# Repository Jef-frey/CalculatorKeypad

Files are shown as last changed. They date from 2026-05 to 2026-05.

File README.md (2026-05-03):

# CalculatorKeypad(WIP)
This project is still a work in progress, the goal is to create a device that can switch between calculator and computer keypad function with the flip of a switch 
keypad_mode
calculator_mode

# Requirements
## Hardware
1x OLIMEX ESP32-S3-DevKit-LiPo development board<br />
1x OLED display<br />
1x battery<br />
1x USB cables<br />
2x slide switch<br />
Switches that fit your application (17 for my project)<br />

## Software
Arduino IDE<br />
U8G2 library<br />
 
# Connection
Pins used and connected for the OLED display are written on the [`oled.cpp`](software/oled.cpp) file and the changable pins are stored on the [`oled.h`](software/oled.h) file, they are for the SPI 256x64 OLED Display with Screen Driver SH1122 used in my project, if a different display is used, a different u8g2 constructor may be used with different connections. And the SPI pins for the OLED display may also need to be changed if a different development board is used.<br />
Pins used for the keypad connections are written on the [`keyboard.h`](software/keyboard.h) file inside the variables KEY_PINS and MODE_SEL_PIN, different pins on the board can be used if available.<br />

# Battery Voltage
The original code from Olimex for battery voltage reading reads the voltage level, to display the voltage as a percentage, a script called [`plotVoltage.ino`](software/battery_level/plotVoltage.ino) is created. It measures the voltage and the time of the measurement and prints the measured values upon request. Part of this code is modified from https://dronebotworkshop.com/esp32-non-volatile-storage/ <br />
To use this script:
1. upload the script with the necessary include files at the same directory
2. charge the device with the battery until it is full
3. unplug the device and press '1' on the keypad
4. wait until the display no longer lights up (run out of power)
5. prepare a program that can accept UART signal and turn the data into a csv file (I used Tera Term for this step)
6. plug in the device at the UART port and press '2' on the keypad
7. plot the csv file

For instance this is the plot of the 420mAh Lipo battery I use
Battery voltage output level curve

# Reference
Software related to battery sensing is from OLIMEX, it's license GPL3 is included in this repository <br />
https://github.com/OLIMEX/ESP32-S3-DevKit-LiPo/blob/main/SOFTWARE/Arduino/ESP32-S3-DevKit-Lipo-bat-sense/ESP32-S3-DevKit-Lipo-bat-sense.ino <br />
Software related to storing data in esp32 and outputing data from esp32 is from https://dronebotworkshop.com/esp32-non-volatile-storage/

# Future plans
Add a case for the device<br />
CalculatorKeypad_case

Use ESP32S3 module instead of a development board, as the development board uses voltage dividers that contribute to leakage current<br />
Implement Bluetooth feature for the keypad<br />

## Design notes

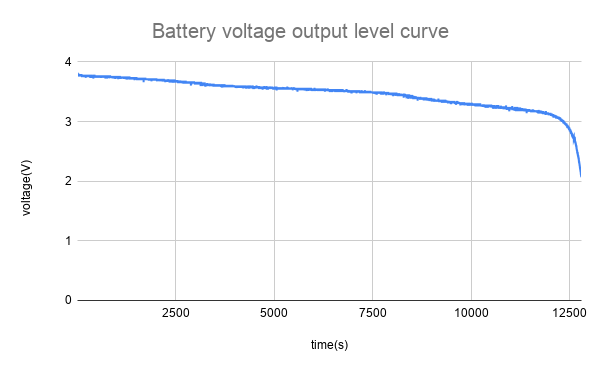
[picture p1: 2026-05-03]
software/battery_level/Battery voltage output level curve.png

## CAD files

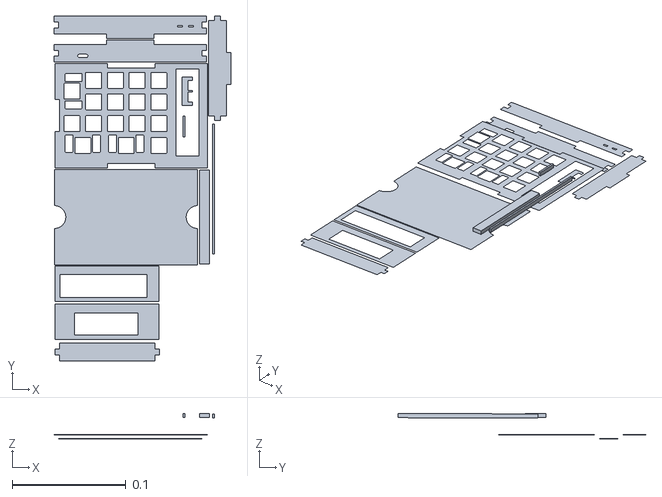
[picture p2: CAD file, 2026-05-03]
hardware/case/cal_numpad.dxf
0.155 x 0.303 x 0.0222

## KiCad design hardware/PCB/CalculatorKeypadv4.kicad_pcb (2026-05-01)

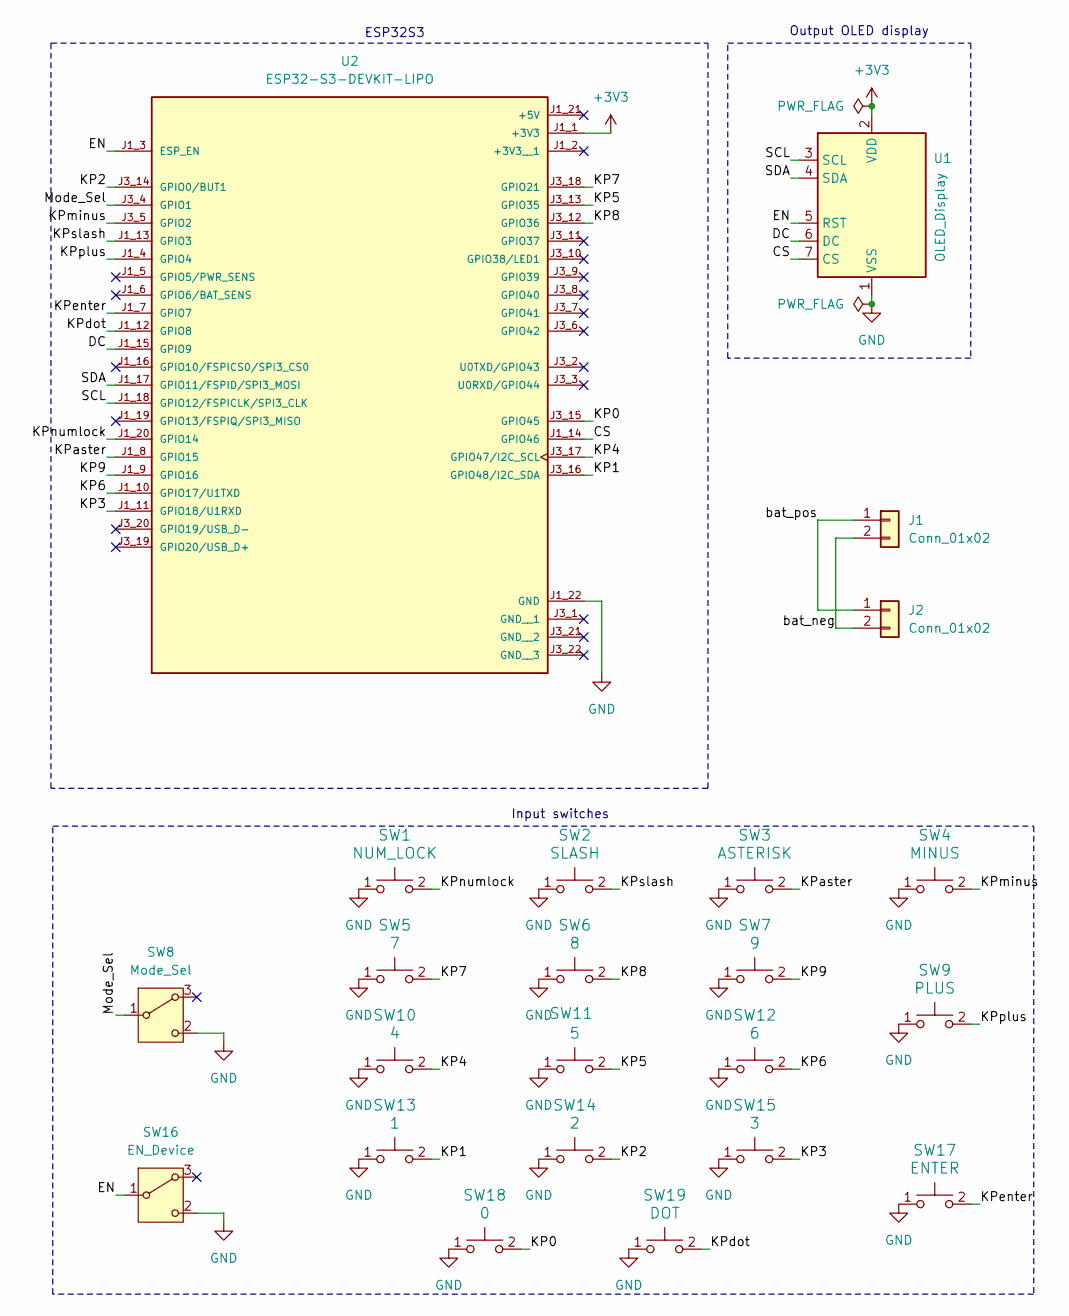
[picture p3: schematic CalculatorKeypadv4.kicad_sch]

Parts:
J1: Conn_01x02; JST_PH_B2B-PH-K_1x02_P2.00mm_Vertical
J2: Conn_01x02; JST_PH_S2B-PH-K_1x02_P2.00mm_Horizontal
SW1: NUM_LOCK; SW_Cherry_MX_1.00u_Plate_w_3Dmodel
SW2: SLASH; SW_Cherry_MX_1.00u_Plate_w_3Dmodel
SW3: ASTERISK; SW_Cherry_MX_1.00u_Plate_w_3Dmodel
SW4: MINUS; SW_Cherry_MX_1.00u_Plate_w_3Dmodel
SW5: 7; SW_Cherry_MX_1.00u_Plate_w_3Dmodel
SW6: 8; SW_Cherry_MX_1.00u_Plate_w_3Dmodel
SW7: 9; SW_Cherry_MX_1.00u_Plate_w_3Dmodel
SW8: Mode_Sel; slide_switch
SW9: PLUS; SW_Cherry_MX_2.00u_Vertical_Plate
SW10: 4; SW_Cherry_MX_1.00u_Plate_w_3Dmodel
SW11: 5; SW_Cherry_MX_1.00u_Plate_w_3Dmodel
SW12: 6; SW_Cherry_MX_1.00u_Plate_w_3Dmodel
SW13: 1; SW_Cherry_MX_1.00u_Plate_w_3Dmodel
SW14: 2; SW_Cherry_MX_1.00u_Plate_w_3Dmodel
SW15: 3; SW_Cherry_MX_1.00u_Plate_w_3Dmodel
SW16: EN_Device; slide_switch
SW17: ENTER; SW_Cherry_MX_2.00u_Vertical_Plate
SW18: 0; SW_Cherry_MX_2.00u_Plate
SW19: DOT; SW_Cherry_MX_1.00u_Plate_w_3Dmodel
U1: OLED_Display; OLED_display
U2: ESP32-S3-DEVKIT-LIPO; XCVR_ESP32-S3-DEVKIT-LIPO; PARTREV B

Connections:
+3V3: U1.2 (VDD), U2.J1_1 (+3V3)
/CS: U1.7 (CS), U2.J1_14 (GPIO46)
/DC: U1.6 (DC), U2.J1_15 (GPIO9)
/EN: SW16.1 (B), U1.5 (RST), U2.J1_3 (ESP_EN)
/KP0: SW18.2, U2.J3_15 (GPIO45)
/KP1: SW13.2, U2.J3_16 (GPIO48/I2C_SDA)
/KP2: SW14.2, U2.J3_14 (GPIO0/BUT1)
/KP3: SW15.2, U2.J1_11 (GPIO18/U1RXD)
/KP4: SW10.2, U2.J3_17 (GPIO47/I2C_SCL)
/KP5: SW11.2, U2.J3_13 (GPIO35)
/KP6: SW12.2, U2.J1_10 (GPIO17/U1TXD)
/KP7: SW5.2, U2.J3_18 (GPIO21)
/KP8: SW6.2, U2.J3_12 (GPIO36)
/KP9: SW7.2, U2.J1_9 (GPIO16)
/KPaster: SW3.2, U2.J1_8 (GPIO15)
/KPdot: SW19.2, U2.J1_12 (GPIO8)
/KPenter: SW17.2, U2.J1_7 (GPIO7)
/KPminus: SW4.2, U2.J3_5 (GPIO2)
/KPnumlock: SW1.2, U2.J1_20 (GPIO14)
/KPplus: SW9.2, U2.J1_4 (GPIO4)
/KPslash: SW2.2, U2.J1_13 (GPIO3)
/Mode_Sel: SW8.1 (B), U2.J3_4 (GPIO1)
/SCL: U1.3 (SCL), U2.J1_18 (GPIO12/FSPICLK/SPI3_CLK)
/SDA: U1.4 (SDA), U2.J1_17 (GPIO11/FSPID/SPI3_MOSI)
/bat_neg: J1.2, J2.2
/bat_pos: J1.1, J2.1
GND: SW1.1, SW2.1, SW3.1, SW4.1, SW5.1, SW6.1, SW7.1, SW8.2 (C), SW9.1, SW10.1, SW11.1, SW12.1, SW13.1, SW14.1, SW15.1, SW16.2 (C), SW17.1, SW18.1, SW19.1, U1.1 (VSS), U2.J1_22 (GND)

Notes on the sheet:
ESP32S3
Input switches
Output OLED display

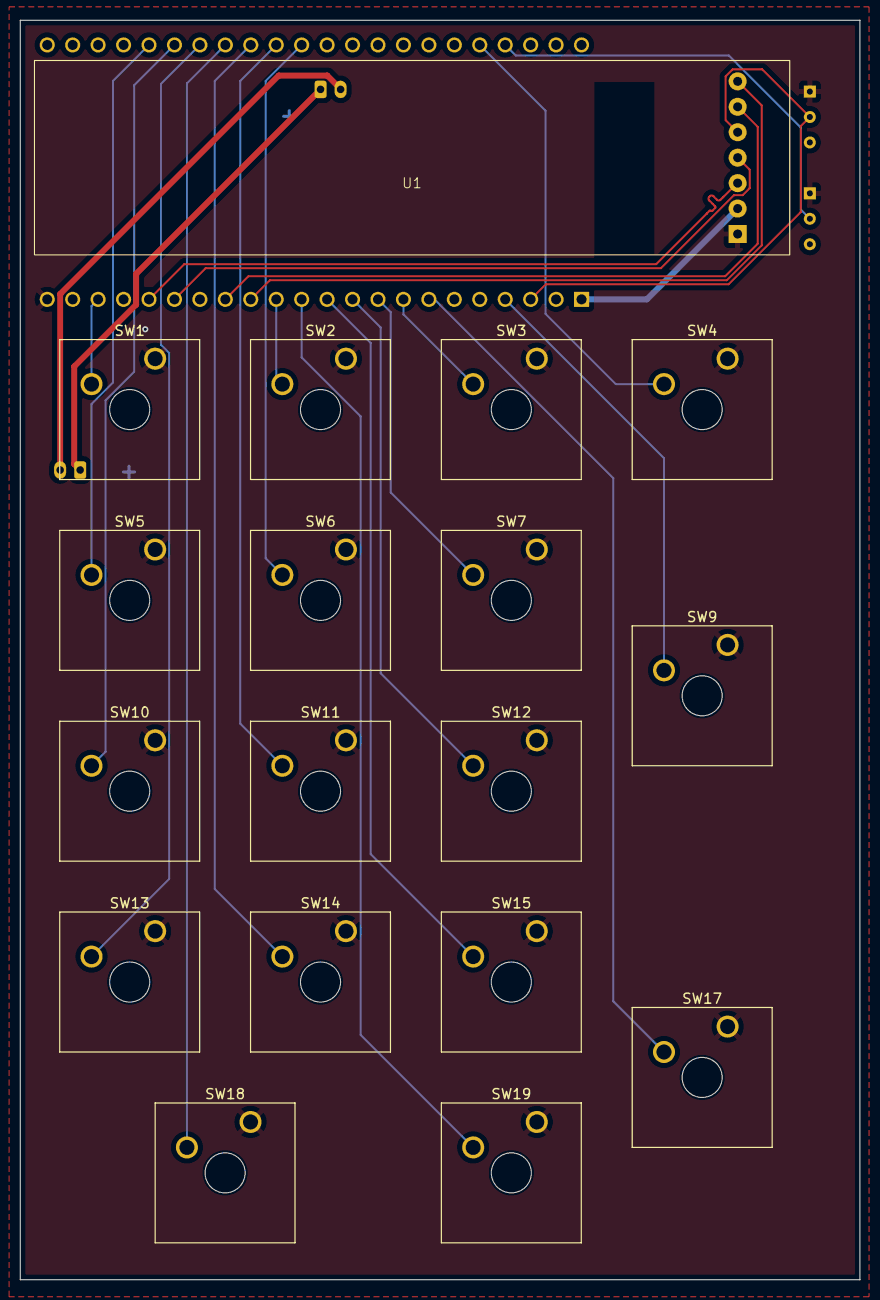
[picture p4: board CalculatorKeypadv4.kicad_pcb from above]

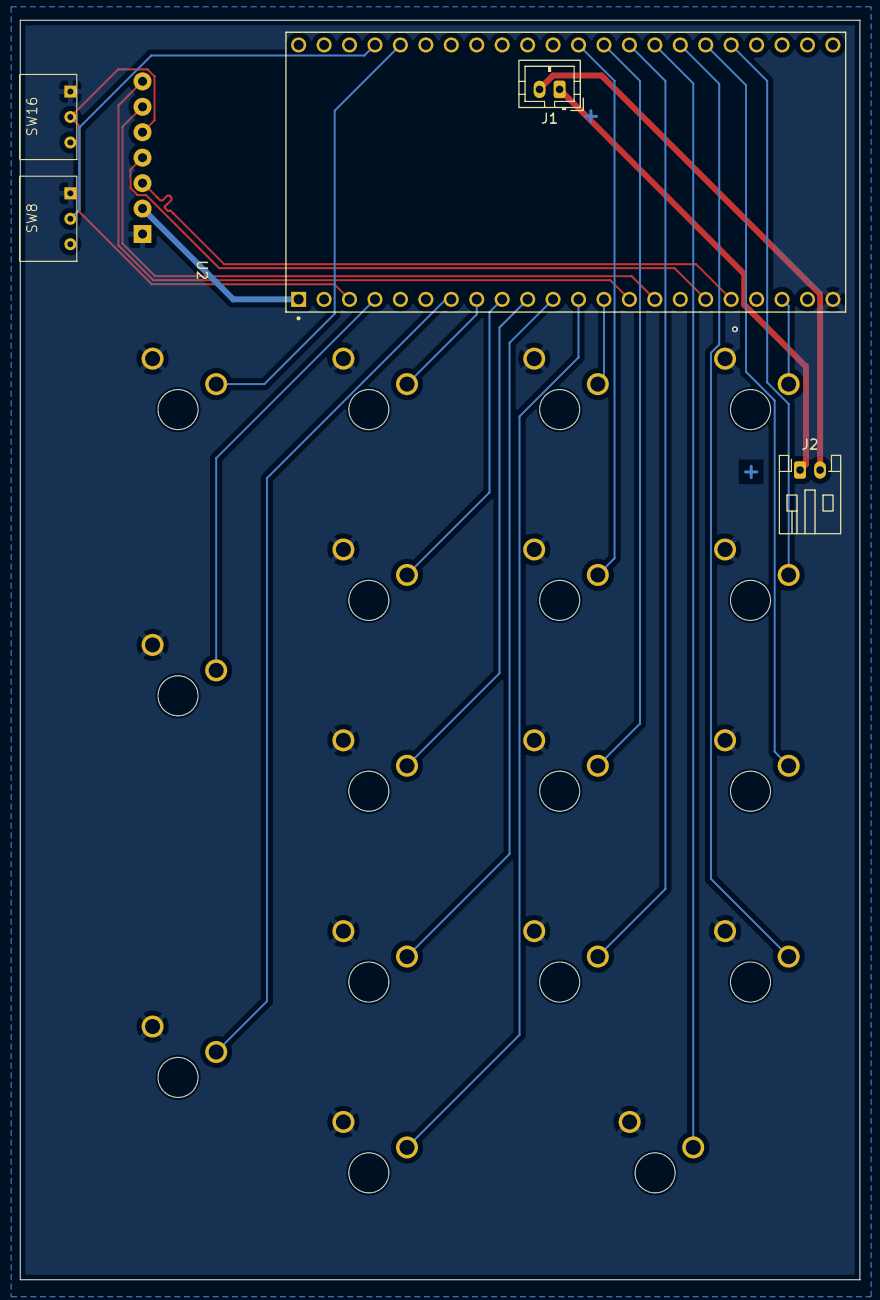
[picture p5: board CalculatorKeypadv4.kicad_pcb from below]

Board: 2 copper layers, 83.8 x 125.7 mm, 23 parts (5 on the bottom side), 27 nets.

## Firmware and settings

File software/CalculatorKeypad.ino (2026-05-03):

#include "control.h"
#include "oled.h"

#include "calculator.h"
#include "calculator_display.h"
#include "keyboard.h"
#include "LinkedList.h"

#include "USB.h"
#include "USBHIDKeyboard.h"

char read_switch;
calculator cal;
USBHIDKeyboard Keyboard;
calculatorkeypad_mode device_mode; 
battery battery_status;
int bat_flag = 1;

void IRAM_ATTR device_mode_control() {
  if (digitalRead(MODE_SEL_PIN) == HIGH) {
    cal.calculator_on();
    device_mode = calculator_mode;
  } else {
    bat_flag = 1;
    battery_status = get_bat_status(bat_flag);
    print_battery(battery_status);
    device_mode = keypad_mode;
    bat_flag = 0;
  }
}

void setup() {  
  // initialization
  control_initialize();
  keyboard_initialize();
  oled_initialize();

  Keyboard.begin();
  USB.begin();

  attachInterrupt(MODE_SEL_PIN, device_mode_control, CHANGE);

  // display the screen's initial state 
  device_mode_control();

}

void loop() {
  read_switch = get_pressed_switch(device_mode);

  if (read_switch != '?') {
    if (device_mode == keypad_mode) {
      Keyboard.write(read_switch);
    } else {
      cal.operate_input(read_switch);
    }
  }

  if (device_mode == keypad_mode) {
    battery_status = get_bat_status(bat_flag);
    print_battery(battery_status);
  }
}

// 

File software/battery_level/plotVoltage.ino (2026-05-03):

// This program stores a csv file of the voltage level of the battery with respect to time
// Pressing "1" in the keypad will start storing the values and pressing "2" of the keypad will upload the file via Serial UART
// Part of the code are modified from https://dronebotworkshop.com/esp32-non-volatile-storage/

#include "control.h"
#include "oled.h"

#include "calculator_display.h"
#include "keyboard.h"

char read_switch;

display_buf display;
calculatorkeypad_mode device_mode = calculator_mode; 

#include <FS.h>
#include <LittleFS.h>

const char* FILE_PATH = "/bat_lvl.csv";
char buf[ARR_SIZE];
int write_flag = 0;
File fh;
#define LOG_INTERVAL 1000
int count = 0;
float voltage_sum = 0;

void setup() {  
  // initialization
  control_initialize();
  keyboard_initialize();
  oled_initialize();
  Serial.begin(115200);

  if (!LittleFS.begin(true)) {
    strcpy(display.top_display,"ERROR: mounting fail");
    print_calculator(display);
    return; 
  } else {
    strcpy(display.top_display,"Device ready");
    print_calculator(display);
  }

}

void loop() {
  read_switch = get_pressed_switch(device_mode);

  if (read_switch == '1') {
    if (write_flag == 0) {
      write_flag = 1;
    } else {
      write_flag = 0;
    }
  } else if (read_switch == '2') {
    String("Uploading file").toCharArray(buf, ARR_SIZE);
    strcpy(display.top_display,buf);
    print_calculator(display);

    fh = LittleFS.open(FILE_PATH, FILE_READ);
    while (fh.available()) {
      Serial.write(fh.read());
    }
    fh.close();

    String("Upload completed").toCharArray(buf, ARR_SIZE);
    strcpy(display.top_display,buf);
    print_calculator(display);

    delay(1000);
  }

  if (write_flag == 1) {
    fh = LittleFS.open(FILE_PATH, FILE_WRITE);
    fh.println("time(s),voltage(V)");
    fh.close();
    write_flag = 2;

    strcpy(display.top_display,"Recording starts");
    print_calculator(display);
    delay(1000);
  } else if (write_flag == 2){

    count++;
    voltage_sum+=readVoltage(BAT_ADC_PIN, BAT_DIVIDER_RATIO);

    static uint32_t t0 = 0;

    if (millis() - t0 >= 1000) {
      t0 = millis();

      String line = String(millis()/LOG_INTERVAL) + "," + String(voltage_sum/count, 8);
      voltage_sum = 0;
      count = 0;

      try {
        fh = LittleFS.open(FILE_PATH, FILE_APPEND);
        fh.println(line);
        fh.close();
      } catch (const std::bad_alloc& e) {
        String("Not enough memory").toCharArray(buf, ARR_SIZE);
        strcpy(display.top_display,buf);
        print_calculator(display);
        return;
      }

      size_t used = LittleFS.usedBytes();
      size_t total = LittleFS.totalBytes();

      String(String(used)+"|"+String(total)).toCharArray(buf, ARR_SIZE);
      strcpy(display.top_display,buf);

      line.toCharArray(buf, ARR_SIZE);
      strcpy(display.bottom_display,buf);

      print_calculator(display);
    }    
  }

}

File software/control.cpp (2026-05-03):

#include "control.h"
#include <arduino.h>

// battery sensor code from OLIMEX will be used 
// https://github.com/OLIMEX/ESP32-S3-DevKit-LiPo/blob/main/SOFTWARE/Arduino/ESP32-S3-DevKit-Lipo-bat-sense/ESP32-S3-DevKit-Lipo-bat-sense.ino

uint16_t bat_read_cnt;
float sum;
float batteryVoltage;

void control_initialize() {
  pinMode(MODE_SEL_PIN, INPUT_PULLUP);
  analogReadResolution(12);

  bat_read_cnt = 0;
  sum = 0;
  batteryVoltage = 0;
}

battery get_bat_status(int bat_flag) {
  battery temp;

  if (bat_flag) {
    batteryVoltage = readVoltage(BAT_ADC_PIN, BAT_DIVIDER_RATIO);
    bat_read_cnt = 0;
  } else {
    bat_read_cnt++;
    sum+=readVoltage(BAT_ADC_PIN, BAT_DIVIDER_RATIO);
    if (bat_read_cnt > BAT_UPDATE_INTERVAL) {
      batteryVoltage = sum/bat_read_cnt;
      sum = 0;
      bat_read_cnt = 0;
    }
  }
  
  uint16_t pwrRawMv = readRawMilliVolts(PWR_ADC_PIN);

  bool externalPowerPresent = (pwrRawMv > PWR_PRESENT_THRESHOLD);

  temp.pwr = externalPowerPresent;
  temp.bat = batteryVoltage;

  return temp;
}

float readVoltage(uint8_t pin, float dividerRatio)
{
  uint32_t adcRaw = analogRead(pin);

  float adcVoltage = (adcRaw / ADC_RESOLUTION) * ADC_REF;
  float realVoltage = adcVoltage * dividerRatio;

  return realVoltage;
}

uint16_t readRawMilliVolts(uint8_t pin)
{
  uint32_t adcRaw = analogRead(pin);
  float adcVoltage = (adcRaw / ADC_RESOLUTION) * ADC_REF;
  return (uint16_t)(adcVoltage * 1000.0);
}

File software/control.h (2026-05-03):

//'control' will have code directly related to the functionalities for battery and mode switching function

// MODE_SEL_PIN is the pin used for switching between calculator mode and keypad mode
// PG_PIN is power good for the battery, indicate any issue with the charging
// CHG_PIN is charging for the battery, indicate if the battery finish charging

// battery sensor code from OLIMEX will be used 

#ifndef CONTROL_H
#define CONTROL_H
#include <cstdint>

enum calculatorkeypad_mode{
  calculator_mode,
  keypad_mode
};

struct battery{
  bool pwr;
  float bat;
};

#define MODE_SEL_PIN   1
#define BAT_ADC_PIN    6    // GPIO6 (Battery)
#define PWR_ADC_PIN    5    // GPIO5 (External power)

//////////////////////////////////////////////////////////////
// ------------- ADC CONFIGURATION -------------------------
//////////////////////////////////////////////////////////////

#define ADC_RESOLUTION 4095.0
#define ADC_REF        3.3

// Correct ratios from schematic
#define BAT_DIVIDER_RATIO  4.1333
#define PWR_DIVIDER_RATIO  5.6808

// 5V through divider gives ~880mV at ADC
// Anything above 400mV means external power present
#define PWR_PRESENT_THRESHOLD 400

#define BAT_UPDATE_INTERVAL 1000

void control_initialize();

// return status of the battery
battery get_bat_status(int bat_flag);

float readVoltage(uint8_t pin, float dividerRatio);

uint16_t readRawMilliVolts(uint8_t pin);

#endif

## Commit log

2025-06-27 Edited the input module, any switch pressed will be displayed onto the OLED display
2025-06-30 Updated the computation function, this stage of calculator is a functioning calculator
2025-07-03 Add files via upload
    Sample code to add the keypad feature
2025-07-03 Add files via upload
    Add an image of the device prototype
2025-07-07 change mode switching method and changed pin locations for PCB layout
2025-07-25 Create sample
    create an image folder
2026-04-28 updated the software for switching to OLIMEX development board
2026-04-28 Added the PCB files and documentation for OLIMEX dev board
2026-04-28 Old images no longer relevant after switching to dev board
2026-04-29 Update LinkedList.cpp
    Solved a bug that crash the device when computing the formula a second time
2026-05-01 Removed the files from zip file
    [CalculatorKeypadv4-B_Cu.gbr, CalculatorKeypadv4-B_Mask.gbr, CalculatorKeypadv4-B_Paste.gbr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]
2026-05-03 Added a script to store the voltage level with respect to time, and then plot it later. the goal is to plot it to calculate battery capacity at different voltage level. Part of the code is taken from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
    [bat_lvl.csv]
2026-05-03 Original the voltage reading is the voltage level at the moment the read function is called, but now the voltage level displayed on the screen will be the average of past voltage reading. The voltage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
2026-05-03 Added the dxf file for the case that will be laser-cut
    [cal_numpad.dxf]
